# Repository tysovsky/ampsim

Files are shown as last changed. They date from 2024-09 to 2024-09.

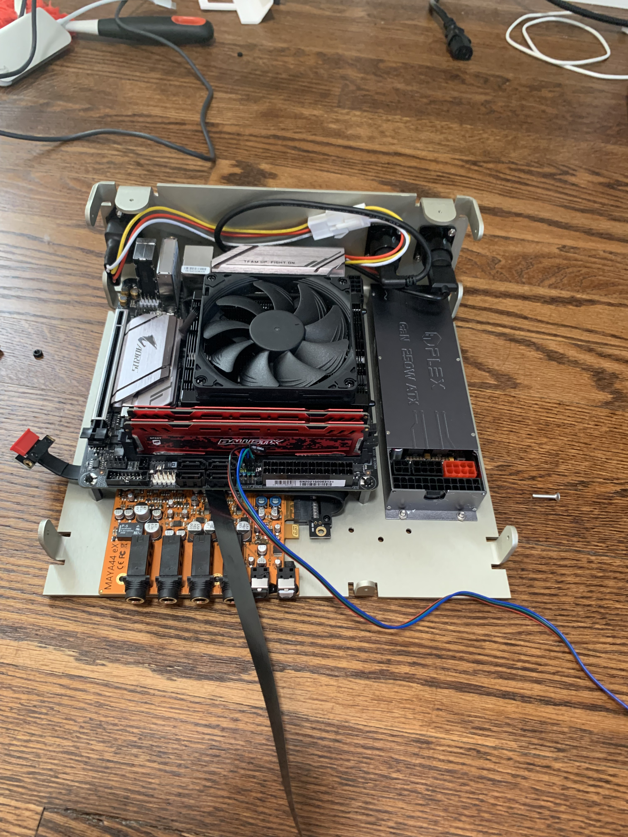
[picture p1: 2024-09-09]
Photos/IMG_1068.jpeg

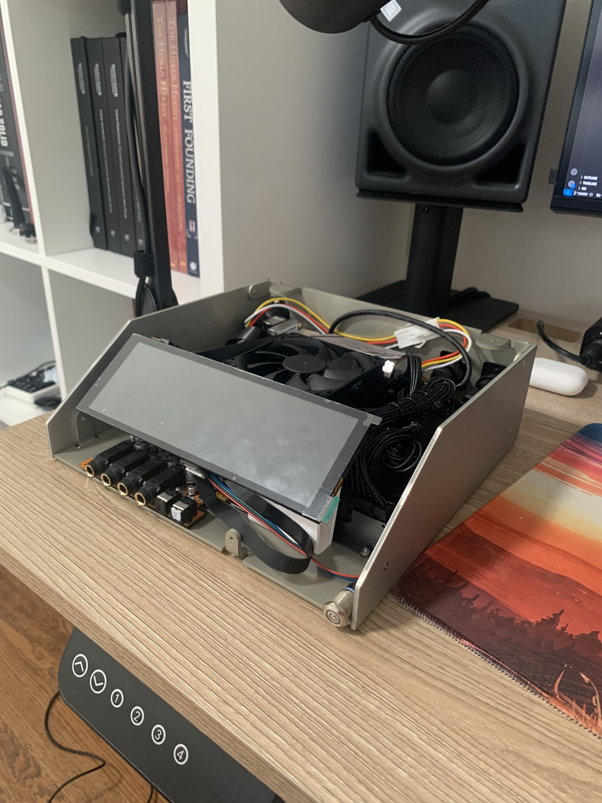
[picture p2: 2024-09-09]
Photos/IMG_1089.jpeg

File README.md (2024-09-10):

CAD Designs and Software for a small dedicated PC used for hosting audio plugins live.

**Bill of materials:**
- **1x Gigabyte B450 I AORUS PRO WIFI + Compatible CPU + Compatible RAM**. Any ITX motherboard will work, however if you want to have a working HDMI port in the back you need a board with two HDMI outs (alternatively you can get HDMI -> Display Port adapter). For the CPU, choose one that can be cooled by a low profile cooler.
- **1x Noctua NH-L9a**: or any other low profile CPU cooler
- **1x Waveshare 7.9inch Capacitive Touch Screen**
- **1x ESI Maya44 EX Audio Interface**
- **1x HDPLEX 250W Power Supply**
- **1x PCIE Riser**
- **7x 90mm 10k Linear Potentiometers**
- **Seeed Studio XIAO SAMD21**: this is used to power the front panel with knobs and a switch
- **6x 20mm Potentiometer Knobs**
- **1x 40mm Potentiometer Knobs**
- **1x QIANRENON HDMI Panel Mount**
- **1x QIANRENON USB C Panel Mount**
- **2x Flat HDMI to HDMI Cable**
- **1x Flat USB A to USB C Cable**
- **1x AC Receptacle**
- **1x Power Button**
- **Various M3 Screws**
- **M3 Standoffs for the Motherboard**

**Manufacturing the case:**

The case is designed to be manufactured on SendCutSend using 0.125" thick aluminum with annodization. The DXF files are setup to be cut, bet, tapped and countersunk on SendCutSend without issues.
The audio interface holder and display holder need to be 3D printed. I recommend using PETG, ABS or other plastic with relatively high glass transition temperature. I suspect that PLA might eventually sag in the case. 

**Software**

The software is a lightweight VST plugin host written in C++ and JUCE. The UI is optimized for small waveshare touchscreen. Build instructions will come later.

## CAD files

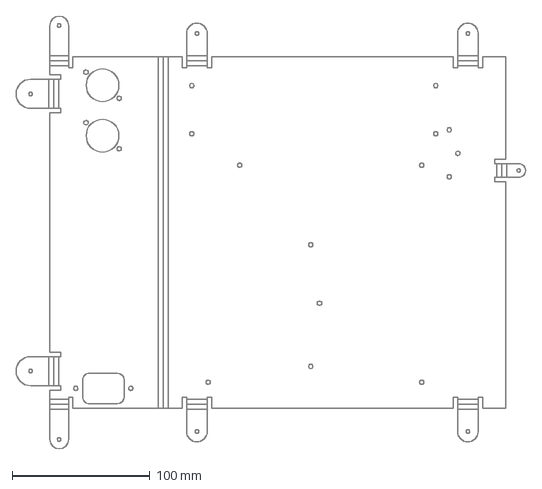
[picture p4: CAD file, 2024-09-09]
DXF/AmpSim_bottom.dxf
369.9 x 313.9 mm

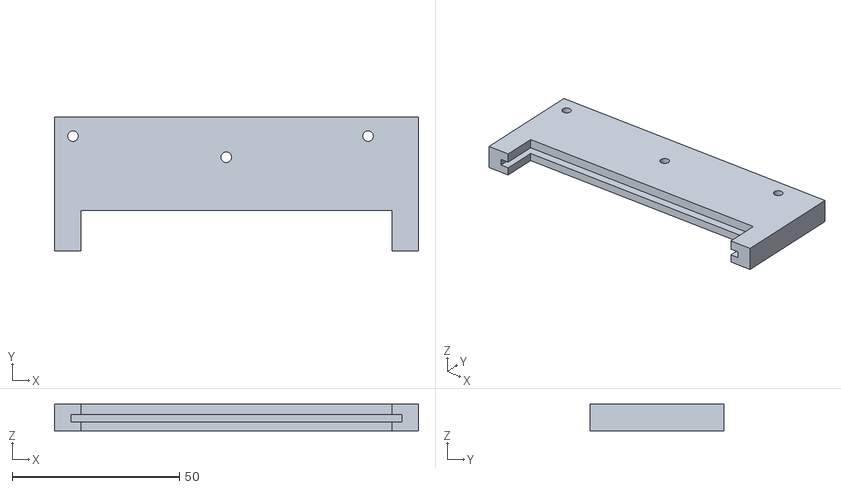
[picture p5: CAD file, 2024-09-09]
STL/Maya44 EX Holder.stl
108.9 x 40.0 x 8.00

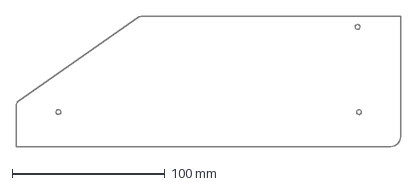
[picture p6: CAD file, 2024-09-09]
DXF/AmpSim_side_right.dxf
251.3 x 85.0 mm

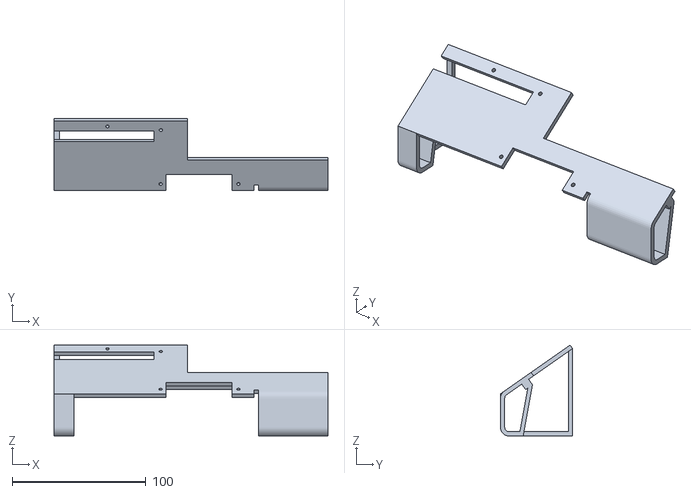
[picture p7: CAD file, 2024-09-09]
STL/Display Holder.stl
205.0 x 53.9 x 68.0

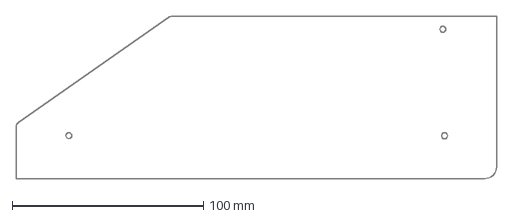
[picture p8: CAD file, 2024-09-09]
DXF/AmpSim_side_left.dxf
251.3 x 85.0 mm

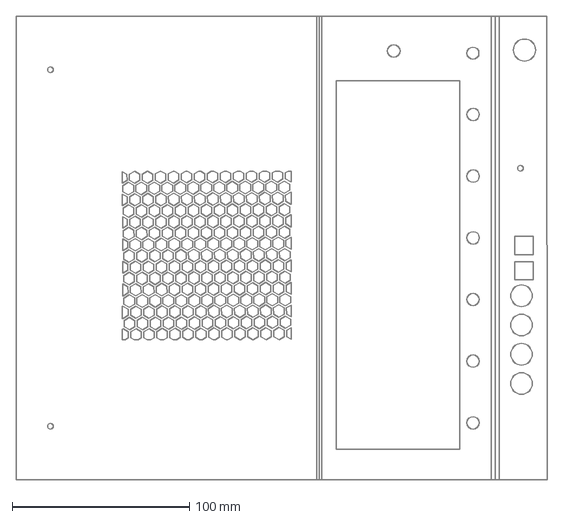
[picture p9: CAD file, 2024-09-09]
DXF/AmpSim_top.dxf
299.6 x 261.4 mm

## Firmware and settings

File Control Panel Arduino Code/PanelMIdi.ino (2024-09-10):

#include <ResponsiveAnalogRead.h>
#include <ButtonDebounce.h>

#include "MIDIUSB.h"

const int NUM_KNOBS = 7;

ResponsiveAnalogRead knobOne(1, true);
ResponsiveAnalogRead knobTwo(5, true);
ResponsiveAnalogRead knobThree(6, true);
ResponsiveAnalogRead knobFour(7, true);
ResponsiveAnalogRead knobFive(8, true);
ResponsiveAnalogRead knobSix(9, true);
ResponsiveAnalogRead knobSeven(10, true);


ResponsiveAnalogRead knobs[NUM_KNOBS] = {
  knobOne,
  knobTwo,
  knobThree,
  knobFour,
  knobFive,
  knobSix,
  knobSeven,
};

int lastSwitchValue = LOW;
ButtonDebounce ampSwitch(2, 250);

void controlChange(byte channel, byte control, byte value) {
  midiEventPacket_t event = {0x0B, 0xB0 | channel, control, value};
  MidiUSB.sendMIDI(event);
}

void noteOn(byte channel, byte note, byte value) {
  midiEventPacket_t event = {0x90, 0x90 | channel, note, value};
  MidiUSB.sendMIDI(event);
}

void noteOff(byte channel, byte note, byte value) {
  midiEventPacket_t event = {0x80, 0x80 | channel, note, value};
  MidiUSB.sendMIDI(event);
}

void midiCommand(byte cmd, byte data1, byte  data2) {
  // First parameter is the event type (top 4 bits of the command byte).
  // Second parameter is command byte combined with the channel.
  // Third parameter is the first data byte
  // Fourth parameter second data byte

  midiEventPacket_t midiMsg = {cmd >> 4, cmd, data1, data2};
  MidiUSB.sendMIDI(midiMsg);
}

void setup() {
  ampSwitch.update();
  lastSwitchValue = ampSwitch.state();
}

void loop() {
  for(int i = 0; i < NUM_KNOBS; i++) {
    knobs[i].update();
    
    if(knobs[i].hasChanged()){
      byte midiValue = 126 - map(knobs[i].getValue(), 0, 1025, 0, 127);
      controlChange(2, 10+i, midiValue);
    }
  }

  handle_switch();

  delay(10);
}

void handle_switch() {
  ampSwitch.update();
  if (ampSwitch.state() != lastSwitchValue) {
    lastSwitchValue = ampSwitch.state();
    if (ampSwitch.state() == HIGH) {
      midiCommand(0x90, 64, 127);
    } else {
      midiCommand(0x80, 64, 0);
    }
  }
}

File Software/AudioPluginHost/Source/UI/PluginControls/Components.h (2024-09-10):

#pragma once

#include <JuceHeader.h>

namespace controls {
	const int LABEL_HEIGHT = 15;


	class Component : public juce::Component {
	public:
		 virtual ~Component() {
			for (auto child : children) {
				delete child;
			}
		}

		void setId(String id) {
			this->id = id;
		}

		void setWidth(String width) {
			this->width = width;
		}

		void addChild(Component* child) {
			this->children.push_back(child);
			addAndMakeVisible(child);
		}

		virtual void resized() override {
			auto localBounds = getLocalBounds();

			auto label = getLabelComponent();
			if (label) {
				label->setBounds(localBounds.removeFromTop(LABEL_HEIGHT));
			}

			int totalPadding = 0;
			for (auto c : getChildren()) {
				totalPadding += c->getPadding();
			}
			int parentWidth = localBounds.getWidth() - totalPadding;

			int totalDesiredWidth = 0;
			int numChildrenWithoutSpecifiedWidth = 0;
			for (auto child : getChildren()) {
				auto desiredWidth = child->getDesiredWidth(parentWidth);
				totalDesiredWidth += desiredWidth;

				if (desiredWidth == 0) {
					numChildrenWithoutSpecifiedWidth++;
				}
			}

			int leftOverWidh = parentWidth - totalDesiredWidth;
			int remainingSiblingWidth = 0;
			if (numChildrenWithoutSpecifiedWidth > 0) {
				remainingSiblingWidth = leftOverWidh / numChildrenWithoutSpecifiedWidth;
			}
			

			for (auto child : getChildren()) {
				localBounds.removeFromLeft(child->getPadding());
				auto desiredWidth = child->getDesiredWidth(parentWidth);
				if (desiredWidth == 0) {
					child->setBounds(localBounds.removeFromLeft(remainingSiblingWidth));
				}
				else {
					child->setBounds(localBounds.removeFromLeft(child->getDesiredWidth(parentWidth)));
				}
			}
		}

		virtual juce::Label* getLabelComponent() {
			return nullptr;
		}

		// Get desired witdth, in pixels
		int getDesiredWidth(int parentWidth) {
			// If width is not specified, compute desired width based on the childre's desired width
			if (width == "") {
				int childrenDesiredWidth = 0;

				for (auto child : getChildren()) {
					childrenDesiredWidth += child->getDesiredWidth(parentWidth);
				}

				return childrenDesiredWidth;
			}

			if (width[width.length() - 1] == '%') {
				auto percentString = width.substring(0, width.length() - 1).toStdString();
				auto percent = std::atoi(percentString.c_str());
				return parentWidth * (percent / 100.0);
			}

			if (width.substring(width.length() - 2, width.length()) == "px")
			{
				return std::atoi(width.substring(0, width.length() - 2).toRawUTF8());
			}

			return 0;
		}

		void setPadding(int padding) {
			this->padding = padding;
		}

		int getPadding() {
			return padding;
		}

		virtual void init() { }

		virtual std::vector<Component*> getChildren() {
			return children;
		}

		virtual void bind(Component* component) { }
		
		void setBindToId(String bindToId)
		{
			this->bindToId = bindToId;
		}

		String getBindToId()
		{
			return bindToId;
		}

		virtual void knobValueChanged(int knobIndex, int value) {
			for (auto c : getChildren()) {
				c->knobValueChanged(knobIndex, value);
			}
		}

		virtual void toggleValueChanged(int toggleIndex, bool enabled) {
			for (auto c : getChildren()) {
				c->toggleValueChanged(toggleIndex, enabled);
			}
		}

		virtual void setValue(int value) {}

	protected:
		String id = "";
		String width = "";
		std::vector<Component*> children;
		int padding = 10;
		String bindToId;
	};

	class IncomingMessageCallback : public juce::CallbackMessage
	{
	public:
		IncomingMessageCallback(Component* o, int value)
			: owner(o), value(value)
		{}

		void messageCallback() override
		{
			if (owner != nullptr)
				owner->setValue(value);
		}

		juce::Component::SafePointer<Component> owner;
		int value = 0;
	};

	class LabeledComponent : public Component {
	public:
		void setLabel(String label) {
			this->label = label;
		}
	protected:
		String label = "";
	};

	class Button : public Component
	{
	public:
		Button(String name) : name(name) {
			button = std::make_unique<juce::TextButton>();
			button->setButtonText(name);
			addAndMakeVisible(button.get());

			button->onClick = [this]() {
				if (disableListener)
					return;

				bool toggled = !button->getToggleState();
				setToggleState(toggled);

				if (param) {
					if (toggled) {
						param->setValue(1.0);
					}
					else
					{
						param->setValue(0.0);
					}
				}
			};
		}
		~Button() {}

		void setParam(AudioProcessorParameter* param) {
			this->param = param;

			if (param->getValue() > 0.5) {
				setToggleState(true);
			}
		}

		void resized() override {
			auto bounds = getLocalBounds();
			button->setBounds(bounds);
		}

		void setToggleState(bool toggled) {
			button->setToggleState(toggled, NotificationType::dontSendNotification);
		}

		juce::Button* getButton() 
		{
			return button.get();
		}

		void setDisableListener(bool disableListener) {
			this->disableListener = disableListener;
		}

		void setToggle(int toggle) {
			this->toggle = toggle;
		}

		void toggleValueChanged(int toggleIndex, bool enabled) override {
			if (toggleIndex == toggle) {
				(new IncomingMessageCallback(this, enabled))->post();
			}
		}

		void setValue(int value) override {
			button->setToggleState(value, juce::NotificationType::dontSendNotification);
			param->setValue(value);
		}


	private:
		String name = "";
		AudioProcessorParameter* param = nullptr;
		std::unique_ptr<juce::TextButton> button = nullptr;
		bool disableListener = false;
		int toggle = -1;
	};

	class Slider : public LabeledComponent {
	public:
		Slider(AudioProcessorParameter* param) : param(param)
		{
			slider = std::make_unique<juce::Slider>();
			slider->setName(param->getName(20));
			slider->setRange(Range<double>(0, 100), 0);
			slider->setValue(param->getValue() * slider->getRange().getEnd());
			slider->setTextBoxStyle(juce::Slider::TextEntryBoxPosition::NoTextBox, true, 0, 0);

			slider->onValueChange = [this, param]() {
				param->setValue(slider->getValue() / slider->getRange().getEnd());
			};

			labelComponent = std::make_unique<juce::Label>();
			labelComponent->setText(param->getName(20), juce::NotificationType::dontSendNotification);
			labelComponent->setJustificationType(Justification::centred);


			addAndMakeVisible(slider.get());
			addAndMakeVisible(labelComponent.get());
		}

		~Slider() {}

		void resized() override {
			auto bounds = getLocalBounds();

			auto labelBounds = bounds.removeFromTop(15);

			labelComponent->setBounds(labelBounds);
			slider->setBounds(bounds);
		}

		void setKnob(int knob) {
			this->knob = knob;
		}

		void setLabel(String label) {
			this->label = label;
			labelComponent->setText(label, juce::NotificationType::dontSendNotification);
		}

		void knobValueChanged(int knobIndex, int value) override {
			if (knobIndex == knob) {
				(new IncomingMessageCallback(this, value))->post();
			}
		}

		void setValue(int value) override {
			slider->setValue(value, juce::NotificationType::sendNotificationAsync);
		}
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

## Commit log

2024-09-10 Software, PCB
    [AmpSim-B_Cu.gbr, AmpSim-B_Mask.gbr, AmpSim-B_Paste.gbr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]
2026-10-23 Make the host build standalone and fix kiosk/touch issues
    Build:
    - CMakeLists.txt now builds from a clean checkout: it fetches JUCE 7.0.12
    and pugixml 1.14 (SHA-256 pinned), lists all sources, and takes the
    bundled assets from the fetched JUCE tree. ASIO is opt-in via
    -DASIO_SDK_DIR.
    - Include pugixml as <pugixml.hpp> instead of a local copy that wasn't
    in the repo.
    - Ignore .vs/ and out/.
    Runtime fixes:
    - Don't crash at startup when the PluginControls folder is missing, and
    skip unreadable or unrelated files instead of stopping the scan.
    - Keep the main window full-screen when another app takes focus: use a
    frameless display-sized window instead of JUCE kiosk mode, which
    Wind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
2026-10-23 Replace the settings side panel with a touch-friendly popup
    The burger menu now opens a window-filling Audio & MIDI settings popup
    laid out for the 1280x400 touchscreen: two columns of 44 px dropdowns
    and buttons for device type, output/input devices, sample rate, buffer
    size, channel pairs, MIDI inputs (toggle buttons) and MIDI output, plus
    a test button, an input level meter and the driver's settings panel
    when one exists.
    A new TouchLookAndFeel makes dropdown items as tall as the box, opens
    lists inside the app window, and spreads long lists over enough
    columns to fit its height, so nothing needs scrolling.
    Device changes made while the popup is open are still saved straight
    away, as wi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
2026-10-23 Experiment: show the graph as a left-to-right signal chain
    Replaces the free-form graph with a single row, in the spirit of the
    Quad Cortex grid: Audio Input on the left, Audio Output on the right,
    and plugins as tiles in between. A round + between each pair of tiles
    opens a touch-sized picker of the scanned plugins and inserts the
    chosen one at that point.
    - Order comes from each node's stored x position, so it's saved with
    the graph and holds even when no audio can reach a plugin. The MIDI
    I/O nodes are hidden.
    - Inserting a plugin rewires the audio prev -> new -> next (a mono
    source feeds every input); deleting one joins its neighbours.
    - The line between tiles is solid where audio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
2026-10-23 Experiment: parallel plugins in the signal chain
    Each step of the chain is now a column of plugins running in parallel.
    A rail in each gap splits the signal into the next column and merges
    it back, and every plugin column has a dashed lane underneath with its
    own +, which adds a plugin in parallel to that column:
    Input -+- Plugin 1 -+- Output
    \----+-----/
    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
2026-10-23 Experiment: per-lane mix control for parallel plugins
    Every plugin inserted into the chain is now followed by a hidden
    "Lane Level" stage (a new internal stereo gain processor with a short
    ramp). It shares its plugin's position, which is how the chain view
    pairs them, and its level is saved with the graph. Audio between
    columns is routed through these stages.
    In columns with more than one plugin, each tile shows a mix bar along
    its bottom edge ("Mix 75%"); touching or dragging the bar sets that
    lane's level from 0 to 100%. Touching elsewhere on the tile still
    selects it, double-taps and long-presses as before. When a column
    drops back to a single plugin its level is reset to 100%, so it isn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
2026-10-23 Add plugin modules, starting with Archetype Tim Henson X
    A plugin's definition file in PluginUIDefinitions can now split it into
    modules that are added to the chain on their own. Adding a module loads
    a full instance of the plugin, applies the file's <Off> settings to
    switch everything off, then applies the module's own settings. Values
    are matched against the plugin's own text for each parameter step.
    ArchetypeTimHensonX.xml defines, from a dump of the plugin's
    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
2026-10-23 Add ParamDump, a tool for mapping a plugin's parameters
    Tools/ParamDump loads a VST3 plugin and writes its parameters to a
    tab-separated file: index, ID, name, label, default and current value,
    step count, and for discrete parameters the text of every step (e.g.
    "Roses | Cherubs | Pink"), which is what the definition files in
    PluginUIDefinitions match their values against. The thousands of
    MIDI CC parameters VST3 plugins expose are left out unless --all is
    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
2026-10-23 Fix plugin modules leaving their own section switched off
    Modules applied the "off" settings and then the module's own settings
    as two passes, so a module's section switch was set Off and then
    straight back On. Archetype Tim Henson X kept the first change and
    lost the second: its editor showed every section disabled, including
    the one the module was for (e.g. Pre FX for the Overdrive module),
    even though the host's cached values said On.
    The module's settings are now merged over the off settings and each
    parameter is set once, to its final value.
2026-10-23 Replace the plugin menu with a full-window grid picker, and add block icons
    The + buttons now open a popup covering the window with a grid of large tiles.
    It starts with a tile per plugin; a plugin with a definition file opens a page
    of its groups (Amps, Pedals) and single modules (EQ), and a group opens a page
    of its modules. "By type" starts from the kinds of block instead, e.g. every
    amp from every plugin. Long pages scroll by dragging, and Back returns to where
    the previous page was scrolled to.
    Blocks get line-art icons for amps, pedals, EQ, whole plugins, plugins split
    into modules, and the input and output. Definition files say what kind each
    module is with an icon attribute on the m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
2026-10-24 Map the other Neural DSP plugins, and show block controls mapped to the pedalboard
    Definition files for Mantra, Parallax X and Soldano SLO-100 X, from their
    ParamDump output, each split into modules with categories that suit it:
    - Soldano SLO-100 X: three amp voicings, six pedals, a cab, a graphic EQ and
    a noise gate.
    - Parallax X (bass): its three-band channel strip as one Bass Distortion
    block, an EQ, a cab and a noise gate.
    - Mantra (vocals): Pitch (correction, harmonies), Dynamics (gate, de-esser,
    compressor, limiter), Tone (EQ, Sculpt, saturation) and Effects (delay,
    reverb, modulation, doubler).
    Archetype Tim Henson X gains a noise gate. New block kinds and icons for cabs,
    dy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
2026-10-24 Spread block controls across the whole width of their panel
    Controls were laid out at the width each needs, from the left, so blocks with
    only a few (a noise gate, a pedal) left most of the panel empty. The width is
    now always shared out in proportion to what each control needs. Knobs, faders,
    switches and lists stay a sensible size in the middle of their share, and a
    choice's buttons grow to half as wide again at most. Each knob or switch
    number now sits next to its label rather than at the edge of the control.
2026-10-24 Save every change to the chain automatically, and drop the Save button
    The graph now saves itself a second after the last change: to what's in it or
    how it's connected, to any plugin's parameters or state (from the block
    controls, the plugin's own window or the pedalboard), to a lane's mix, or to a
    block's bypass. Each plugin's changes are listened for as well as the graph's,
    and nothing is written when the saved text hasn't changed.
    A graph without a file of its own is saved to Chain.filtergraph next to the
    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
2026-10-24 Give the chain view several chains, each with its own inputs and outputs
    Each chain now starts with input blocks and ends with output blocks, which pick
    the audio device's channels: one channel or a pair of the first eight. An input
    takes every device input and passes on its channel (a single one to both sides
    of the chain); an output sends the chain to its channel (both sides mixed) or
    pair. Picking a channel is a parameter change, on the block's controls, so it
    doesn't rewire the graph and is saved like any other change. The device's
    channels are connected to the inputs and outputs again whenever the device
    changes, so a channel the device didn't have before works once it does.
    Add chain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
2026-10-24 Record each output to WAV files, and play recordings back
    Record in the title bar records what goes to each output in use: each channel,
    or pair, that a chain's output block sends to, as a 24-bit WAV file of its own
    (a mono file for a single channel, stereo for a pair). Outputs that more than
    one chain sends to are recorded as the mix the device gets. While it records,
    the button turns red and shows how long it's been going; tapping it again
    stops and finishes the files. They go in a Recordings folder next to the app's
    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
2026-10-24 Add a delete button to each recording in the recordings list
    A bin at the right-hand end of each row deletes that recording, moving the
    file to the Recycle Bin so one deleted by mistake on the touchscreen can still
    be got back. Tapping anywhere else in the row still opens the player.
2026-10-24 Rename recordings on an on-screen keyboard
    A pencil left of each recording's bin opens a popup with the recording's name
    and an on-screen keyboard, as the device has no keyboard: numbers, letters,
    the punctuation file names allow, Shift for a capital, Backspace and arrow keys
    that repeat while held, and a space bar, with Done and Cancel. The name starts
    selected, so typing replaces it. A keyboard plugged in works too.
    The file keeps the time it was started at the front of its name, so the list
    still shows when it was made and keeps it in the same place. A name another
    recording already has gets a number added.
    The keyboard is its own component, TextEntryPopup, so other places that need
    a n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
2026-10-24 Rename chains' inputs and outputs, and stop the chain view updating inside an update
    Inputs and outputs can be given names of their own, e.g. "Guitar" or "Main",
    from Rename in their long-press menu, on the same on-screen keyboard as
    recordings. The tile shows the name, with the channel underneath when there's
    room; leaving it blank, or as the channel, goes back to the channel. The name
    is saved with the channel in the block's state (inputs and outputs saved
    without one still load), and recordings of a named output are named after it.
    The host crashed in GraphEditorPanel::updateComponents, on a tile pointer that
    was no longer valid. Removing a tile tells the listeners, and the document
    then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
2026-10-24 Leave the cab off in the Soldano's amp blocks
    The Soldano's amp blocks turned its cab section on as well as the amp, so a
    Cab block after one ran two cabs. They now leave it off, like the other
    plugins' amp blocks, for a Cab block after them. Blocks already in a chain
    keep the plugin state they were saved with.
2026-10-24 Only offer plugins' parts in the picker, and reopen it by plugin or type as last left
    A plugin that's split into modules can now only be added as one of them:
    its page no longer starts with a Full plugin tile, and By type no longer
    lists it with the plugins that aren't split. Those plugins can still be added
    whole, as before. Whole-plugin blocks already in a chain are kept.
    The picker remembers whether it was last showing By plugin or By type, in
    the app's settings, and opens that way the next time, also after a restart.
2026-10-24 Turn blocks on and off by bypassing them, not with a switch of their own
    Every module's controls had a switch for its own effect, section or EQ
    (Comp, Drive, Delay, Gate, EQ, ...). A block is turned on and off by holding
    it and choosing Bypass, so those switches are gone from all the definition
    files: 68 of them across Tim Henson, Nolly, Petrucci, Rabea, Fortin, Soldano,
    Parallax and Mantra. Each module's settings already turn its effect on when
    it's added; Tim Henson's EQ module now also turns on each amp's EQ, which it
    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
2026-10-24 Rearrange blocks by dragging them onto a +
    A plugin's tile can now be dragged to another place: onto a + between two
    blocks to put it there in series, onto a + under a column to run it in
    parallel with that column, in its own chain or another. While it's dragged
    the tile follows the finger, see-through; a dashed outline shows where it
    was; only the +s it can go to are shown; and the one it would go to, the
    nearest within reach of the finger, is lit up on top of it. Let go anywhere
    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
2026-10-24 Delete a block by dragging it off into empty space
    A dragged block let go away from every tile and every + is now deleted, as
    Delete in its hold menu does. While it's over such empty space its tile turns
    red with a bin instead of its icon, so it's clear what letting go will do.
    Let go over a tile, or near any + (including the hidden ones either side of
    where it is), and it goes back as before, so putting a block down near where
    it came from doesn't delete it.
    The bin is shared with the recordings list's delete button, from BlockIcons.
2026-10-25 Play Arturia Pigments from the host, with a full-screen touch editor
    Synths can now be added to a chain and played. The graph connects its MIDI
    input to every instrument block (not to effects, so notes can't set off
    whatever an amp sim has mapped to MIDI), and MIDI from every input device
    reaches it apart from the pedalboard's, whose switch sends a note.
    A block's definition file can now give it a full-screen editor: an <Editor>
    of pages, each picked with a tab along the top, made of rows of controls and,
    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
2026-10-26 Draw a synth's sound on its Play page instead of a keyboard
    A MIDI controller plays the synth, so the on-screen keyboard is gone. In its
    place, a block editor page can have a <Visualiser/>: a glowing cloud of
    particles above the page's rows that moves with the block's sound, like
    Pigments' own Play view. It drifts and breathes while it's quiet; playing
    makes it brighter and swirl faster, the bass swells it, each loud note bursts
    it outwards with a ring rippling out, and the highs make it sparkle and
    turn it white.
    It hears the block through its lane level stage, which now keeps the last
    2048 samples coming in (mixed to mono), for anything that wants to draw the
    sound. The visualiser reads t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
2026-10-26 Put free links behind a setting, off to start with
    The chains are a grid again unless "Free links (experimental)" is ticked in
    the header of the settings popup: each column feeds the whole of the next
    through a rail, tiles have no dots, holding a link or a + doesn't remove
    anything, and adding, moving and removing blocks join whole columns, as
    before there were links. Ticking it brings the links back. Turning it on or
    off doesn't change how anything's connected, and it's kept with the app's
    settings.
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
